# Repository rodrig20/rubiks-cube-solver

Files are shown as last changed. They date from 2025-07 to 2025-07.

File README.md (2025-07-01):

# Rubik's Cube Solver

Um sistema robótico completo para resolver automaticamente um Cubo de Rubik, controlado por um microcontrolador ESP32-CAM. Este projeto combina hardware robótico (motores, câmera) com software de resolução e uma interface web interativa para visualização e controlo.

## Funcionalidades

- **Resolução Automática**: Algoritmo ZZ para resolver qualquer configuração do Cubo de Rubik
- **Captura de Imagem**: Câmara ESP32-CAM para detetar automaticamente o estado do cubo
- **Controlo Robótico**: Sistema de motores para executar movimentos físicos no cubo
- **Interface Web**: Visualização 3D interativa e controlo remoto via navegador
- **Baralhamento**: Função para gerar configurações aleatórias

## Requisitos de Hardware

### Componentes Principais
- **Microcontrolador**: ESP32 com suporte a câmera (ESP32-CAM ou similar)
- **Câmara**: Módulo ESP32-CAM para deteção de cores
- **Motores**:
  - Motor de base para rotação do cubo
  - Motor de garra para segurar e girar faces
- **Estrutura Mecânica**: Suporte para o cubo, motores e câmara
- **LED**: Iluminação para captura de imagem (embutido no ESP32-CAM)

### Conectividade
- Rede Wi-Fi para comunicação com interface web

## Dependências de Software

### Arduino IDE
- Testatado no Arduino IDE 2.3.4
- Pacote de suporte para placas ESP32
- Bibliotecas necessárias:
  - `ArduinoJson` - Parsing de JSON
  - `LittleFS` - Sistema de ficheiros
  - `WiFi` - Conectividade Wi-Fi (ESP32)
  - `WebServer` - Servidor web (ESP32)
  - `esp_camera` - Controlo da câmera ESP32-CAM

### Ferramentas Python (opcional)
- Python 3.7+
- Dependências em `tools/requirements.txt`:
  - `beautifulsoup4` - Web scraping
  - `requests` - Requisições HTTP
  - `RubikTwoPhase` - Algoritmo de resolução

## Instalação

1. Instalar o Arduino IDE e o pacote de suporte para placas necessário
2. Instalar as bibliotecas necessárias através do Gestor de Bibliotecas do Arduino
3. Fazer clone deste repositório ou descarregar o código fonte
4. Carregar os ficheiros do sistema de ficheiros para o ESP32 utilizando a ferramenta de carregamento LittleFS
5. Compilar e carregar o sketch principal para a placa

## Utilização

### 1. Inicialização do Sistema
1. Ligar a placa ESP32
2. Aguardar inicialização (ver mensagens no Monitor Série)
3. Conectar à rede Wi-Fi "CubeSolver" (password: "#cubeSolver")
4. Notar o endereço IP mostrado no Monitor Série

### 2. Interface Web
1. Abrir navegador e aceder ao IP do ESP32 (ex: `192.168.4.1`)
2. A interface 3D do cubo será carregada
3. Utilizar controlos para:
   - Visualizar o cubo em 3D
   - Executar movimentos manuais
   - Capturar estado atual via câmara
   - Resolver automaticamente
   - Baralhar o cubo

### 3. API Endpoints
- `GET /cubestate` - Obter estado atual do cubo
- `POST /sendmove` - Executar sequência de movimentos
- `GET /solve` - Resolver o cubo e retornar solução
- `GET /scramble` - Baralhar o cubo
- `GET /capture` - Capturar imagem da câmera (debug)
- `POST /update_state` - Atualizar estado do cubo
- `GET /scan` - Faz o scan do estado do cubo via câmera

## Estrutura do Projeto

### Ficheiros Principais
- `rubiks-cube-solver.ino` - Sketch principal do Arduino
- `Robot.hpp/cpp` - Principal
- `Solver.hpp/cpp` - Algoritmo de resolução do cubo
- `Camera.hpp/cpp` - Controlo da câmara e processamento de imagem
- `Motor.hpp/cpp` - Classes base para controlo de motores
- `BaseMotor.hpp/cpp` - Motor de rotação da base
- `GrabberMotor.hpp/cpp` - Motor da garra

### Interface Web (`data/`)
- `index.html` - Página principal
- `css/style.css` - Estilos da interface
- `js/` - Bibliotecas JavaScript:
  - `css3.oz.js`, `oz.js`, `quaternion.js`, `rubik.js` - Cubo virtual
  - `custom.js` - Integração com ESP32

### Ferramentas (`tools/`)
- `get_zbll.py` - Geração de algoritmos ZBLL
- `requirements.txt` - Dependências Python

### Rede Wi-Fi
- Modificar SSID e password em `rubiks-cube-solver.ino`
- Configurar IP estático se necessário

## Créditos
- **Cubo Virtual**: Baseada em [ondras/rubik](https://github.com/ondras/rubik)

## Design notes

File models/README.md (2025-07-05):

# Modelos 3D

Esta pasta contém os arquivos STL necessários para a construção física do robô solucionador do Cubo Mágico.

## Arquivos Usados

### Arquivos Personalizados
- **ESP32Cam-suporte.stl** - Suporte para a base deslizante
- **ESP32Cam-deslizante.stl** - Base deslizante para controlar a câmera do ESP32-CAM

### Projeto Original

Os modelos 3D deste projeto são do trabalho original disponível no Thingiverse:

🔗 **[CUBOTino autonomous: 3D printed Rubik's cube solver](https://www.thingiverse.com/thing:5407226)**

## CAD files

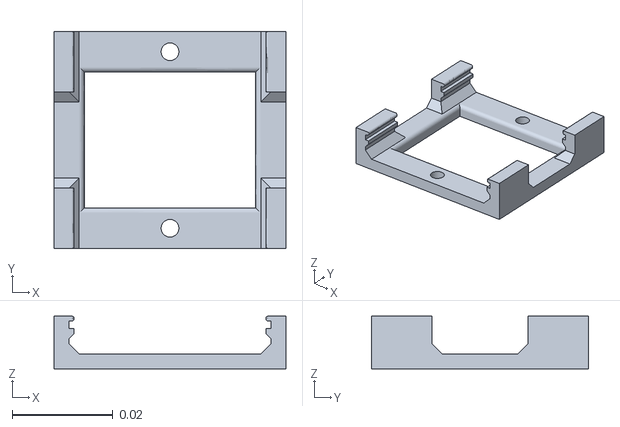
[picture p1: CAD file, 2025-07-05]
models/ESP32Cam-deslizante.stl
0.046 x 0.043 x 0.0105

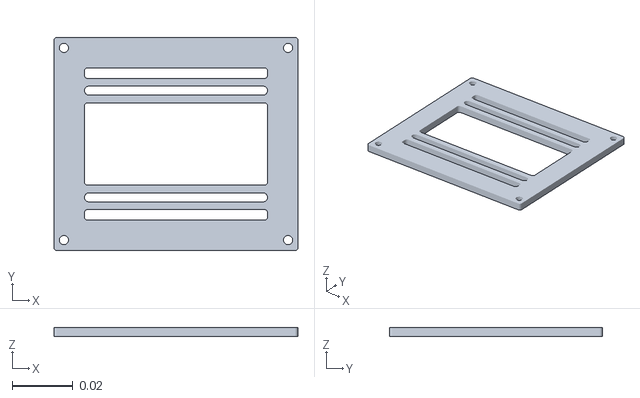
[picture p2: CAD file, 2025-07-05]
models/ESP32Cam-suporte.stl
0.08 x 0.07 x 0.003

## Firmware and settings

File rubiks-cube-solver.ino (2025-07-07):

#include <Arduino.h>
#include <LittleFS.h>
#include <WiFi.h>

#include "src/Robot.hpp"

Robot* robot = nullptr;

// Tenta gerar uma seed o mais próxima de aleatório
void randomSeed() {
    // Inicializar gerador de números aleatórios com seed única
    // Usar múltiplas fontes de aleatoriedade para garantir unicidade
    unsigned long seed = 0;

    // Usar tempo de inicialização (micros() para maior precisão)
    seed += micros();

    // Usar endereço MAC do WiFi
    uint8_t mac[6];
    WiFi.macAddress(mac);
    for (int i = 0; i < 6; i++) {
        seed = seed * 31 + mac[i];
    }

    // Usar ID único do chip ESP32
    seed += ESP.getEfuseMac();

    // Usar tempo de boot (em milissegundos)
    seed += millis();

    // Aplicar a seed
    srand(seed);

    Serial.printf("Seed inicializada: %lu\n", seed);
}

void setup() {
    // Iniciar o Serial
    Serial.begin(115200);
    delay(1000);
    Serial.println("\nIniciando ...");

    randomSeed();

    // Iniciar o LittleFS
    if (!LittleFS.begin()) {
        Serial.println("Falha ao montar LittleFS! A formatar...");
        LittleFS.format();
        if (!LittleFS.begin()) {
            Serial.println("Erro: Não foi possível montar LittleFS!");
            return;
        }
    }

    robot = new Robot();

    // Mensagem Final
    Serial.println("Servidor HTTP iniciado!");
}

void loop() {
    // Executar robô
    robot->run();
}

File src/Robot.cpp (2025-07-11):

#include "Robot.hpp"

#include <Arduino.h>
#include <Wire.h>
#include <esp_system.h>

#include <iostream>
#include <map>
#include <sstream>
#include <string>

#include "camera/Camera.hpp"
#include "motors/BaseMotor.hpp"
#include "motors/GrabberMotor.hpp"
#include "network/CubeServer.hpp"
#include "solver/Solver.hpp"

#define ERROR_LED_PIN 33
#define NO_ROBOT 0  // Indica se o esp32 está ligado ao robô

// Verifica se um dispositivo I2C está conectado
int device_is_present(uint8_t address) {
    Wire.beginTransmission(address);
    return (Wire.endTransmission() == 0);
}

// Pisca o led de Erro
void blink_erro(int times) {
    for (int i = 0; i < times; i++) {
        digitalWrite(ERROR_LED_PIN, LOW);
        delay(75);
        digitalWrite(ERROR_LED_PIN, HIGH);
        if (times - 1 != i) {
            delay(100);
        }
    }
}

// Inicia a comunicação I2C
Adafruit_PWMServoDriver* Robot::initI2C() {
    Wire.begin(14, 15);  // Inicializa I2C nos pinos 14 e 15

    if (!device_is_present(0x40)) {
        return nullptr;  // Ou lidar com erro como quiseres
    }

    Adafruit_PWMServoDriver* new_pwm = new Adafruit_PWMServoDriver(0x40);
    new_pwm->begin();
    new_pwm->setPWMFreq(50);
    return new_pwm;
}

// Move os dois motores para a posição padrão
void Robot::init_config() {
    virtual_lock_default();
    virtual_turn_90_aligned(0);
}

// Aplica um movimento ao cubo causado pelas rotações da base
void Robot::change_virtual_orientation(int changes[6]) {
    string temp = cube_state;
    for (int i = 0; i < 6; i++) {
        temp[i] = cube_state[changes[i]];
    }

    cube_state = temp;
}

// Aplica a uma sequencia de movimentos dos motores para uma certa face ficar
// para baixo
void Robot::rotate_to_side(const char side) {
    int side_idx;
    for (int i = 0; i < cube_state.size(); i++) {
        if (cube_state[i] == side) {
            side_idx = i;
            break;
        }
    }

    switch (side_idx) {
        // Topo
        case 0: {
            virtual_spin(2);
            int pattern0[6] = {5, 3, 2, 1, 4, 0};
            change_virtual_orientation(pattern0);
            break;
        }
        // Frente
        case 1: {
            virtual_spin(1);
            int pattern1[6] = {3, 0, 2, 5, 4, 1};
            change_virtual_orientation(pattern1);
            break;
        }
        // Direita
        case 2: {
            virtual_turn_90_aligned(1);
            virtual_spin(3);
            virtual_turn_90_aligned(0);
            int pattern2[6] = {4, 1, 0, 3, 5, 2};
            change_virtual_orientation(pattern2);
            break;
        }
        // Trás
        case 3: {
            virtual_spin(3);
            int pattern3[6] = {1, 5, 2, 0, 4, 3};
            change_virtual_orientation(pattern3);
            break;
        }
        // Esquerda
        case 4: {
            virtual_turn_90_aligned(1);
            virtual_spin(1);
            virtual_turn_90_aligned(0);
            int pattern4[6] = {2, 1, 5, 3, 0, 4};
            change_virtual_orientation(pattern4);
            break;
        }
    }
}

// Passar o movimento spin para o buffer
void Robot::virtual_spin(int times) {
    for (int i = 0; i < times; i++) {
        this->move_list += "U P ";
    }
}

// Passar o movimento lock para o buffer
void Robot::virtual_lock() { this->move_list += "L "; }

// Passar o movimento da garra para o default para o buffer
void Robot::virtual_lock_default() { this->move_list += "P "; }

// Passar o movimento em 90º alinhado para o buffer
void Robot::virtual_turn_90_aligned(int clockwise) {
    if (clockwise) {
        this->move_list += "A ";
    } else {
        this->move_list += "A' ";
    }
}

// Passar o movimento em 90º para o buffer
void Robot::virtual_turn_90(int clockwise) {
    if (clockwise) {
        this->move_list += "T ";
    } else {
        this->move_list += "T' ";
    }
}

// Passar o movimento em 180º para o buffer
void Robot::virtual_turn_180(int clockwise) {
    if (clockwise) {
        this->move_list += "D ";
    } else {
        this->move_list += "D' ";
    }
}

// Passar a captura de imagem para o buffer
void Robot::virtual_camera(int face) {
    this->move_list += "C" + std::to_string(face) + " ";
}

// Construtor
Robot::Robot() {
    pinMode(ERROR_LED_PIN, OUTPUT);
    this->cube = new Solver(Solver::solved_string());
    has_state = 1;
    this->server = new CubeServer(this, 80);

// Executa se o ESP32 está conectado ao robô
#if !NO_ROBOT
    this->pwm = initI2C();

    // Inicializar motores/câmara
    if (!pwm) {
        std::cout << "I2C não detetado. A reiniciar..." << std::endl;
        // Avisa do reinicio e volta a ligar
        blink_erro(2);
        esp_restart();
        return;
    }
    this->base = new BaseMotor(this->pwm, 0);
    this->grabber = new GrabberMotor(this->pwm, 1);

    this->cam = new Camera();
    if (!this->cam->initialized) {
        std::cout << "Câmara não detetada. A reiniciar..." << std::endl;
        // Avisa do reinicio e volta a ligar
        blink_erro(3);
        esp_restart();
        return;
    }

    init_config();

#endif

    // Pisca o LED para indicar que está pronto
    for (int i = 0; i < 3; i++) {
        analogWrite(LED_PIN, LED_BRIGHTNESS);
        delay(75);
        analogWrite(LED_PIN, 0);
        delay(75);
    }
}

// Baralha o cubo
std::string Robot::scramble(int size) {
    std::string move_sequence = cube->scramble(size);
    virtual_move(move_sequence);
    return move_sequence;
}

// Resolve o cubo
std::string Robot::solve() {
    std::string move_sequence = cube->solve();
    virtual_move(move_sequence);
    return move_sequence;
}

// Ativa a sequencia de motores para girar a face de baixo em 90º
void Robot::turn_face(int clockwise) {
    if (clockwise) {
        virtual_lock();
        virtual_turn_90(1);
        virtual_lock_default();
        virtual_turn_90_aligned(0);
        int pattern[6] = {0, 2, 3, 4, 1, 5};
        change_virtual_orientation(pattern);
    } else {
        virtual_turn_90_aligned(1);
        virtual_lock();
        virtual_turn_90(0);
        virtual_lock_default();
        virtual_turn_90_aligned(0);
        int pattern[6] = {0, 4, 1, 2, 3, 5};
        change_virtual_orientation(pattern);
    }
}
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

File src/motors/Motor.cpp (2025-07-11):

#include "Motor.hpp"

#include <Arduino.h>

// Construtor que armazen o motor_id e pwm
Motor::Motor(Adafruit_PWMServoDriver *pwm, int motor_id) {
    this->pwm = pwm;
    this->motor_id = motor_id;
}

void Motor::turn_with_speed_to(float angle, int speed_percent) {
    final_angle = angle;
    // Angulo inicial
    if (this->angle == -1) {
        steps_remaning = 1;
    } else {
        // Calcular o número de steps
        int divisor = (SERVO_STEP_SIZE * (speed_percent / 100.0f));
        steps_remaning = abs(angle - this->angle) / divisor;
    }
}

// Configura o motor girar para um angulo escolhido numa velocidade rápida
void Motor::turn_fast_to(float angle) { turn_with_speed_to(angle, 100); }

// Configura o motor girar para um angulo escolhido com metade da velocidade
void Motor::turn_slow_to(float angle) { turn_with_speed_to(angle, 50); }

// Aplica um delay com millis
void Motor::dly(int millis_time) { next_move_time = millis() + millis_time; }

// Aplica o próximo passo do movimento do motor
int Motor::step() {
    // Verifica se já passou o tempo definido
    if (next_move_time < millis()) {
        // Se o angulo já chegou ao fim atualiza
        if (current_angle == final_angle) {
            // Atualiza e retorna que já acabou
            this->angle = final_angle;
            return 1;
        }

        // Verifica se o angulo é muito pequeno ou for o ultimo step
        if (abs(final_angle - this->angle) < 30 || steps_remaning <= 1) {
            // Atualiza a var da posição atual e moev até ao final
            current_angle = final_angle;
            (*pwm).setPWM(motor_id, 0, angleToPulse(final_angle));
            dly(SERVO_MOVE_DELAY);
        } else {
            // Trocar a var da posição atual para o próximo passo
            current_angle += (final_angle - current_angle) / steps_remaning;
            steps_remaning--;

            (*pwm).setPWM(motor_id, 0, angleToPulse(current_angle));
            dly(SERVO_STEP_DELAY);
        }
    }

    return 0;
}

// Transforma angulo em pwm
uint16_t Motor::angleToPulse(float angle) {
    return SERVO_MIN + ((angle * (SERVO_MAX - SERVO_MIN)) / 270);
}

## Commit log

2025-03-26 Trocar Refactor.ino por rubiks-cube-solver.ino para que possa ser aberto no Arduino IDE
2025-03-26 Corrigir problemas de indentação
    [rubiks-cube-solver.ino]
2025-03-26 Corrigir nome da classe do WebServer do Esp8266
    [rubiks-cube-solver.ino]
2025-03-27 Atualizar conteudo do README para coincidir com o estado atual do projeto
2025-03-31 Começar o loop em 4, em vez de somar +4 em todos os usos
2025-03-31 Simplificar condição para identificar o local das edges de pares F2L
2025-05-08 Basic camera
2025-05-27 Fix color detection (endian problem)
    [Camera.cpp, Camera.hpp]
2025-05-27 Remove unused jpeg_quality field from ESP32 camera config
2025-05-27 Set sensor tuning params: brightness, contrast, saturation, white balance and auto exposure/gain
2025-05-29 Criar classe abstrata de um Motor
2025-05-29 Cria a classe dos dois tipos de motor (Base e Grabber)
2025-06-17 Fix alignment issues in BaseMotor
    [BaseMotor.cpp, Robot.cpp]
2025-06-17 Fix speed and timing synchronization between motors
    [Motor.cpp, Motor.hpp, Robot.cpp]
2025-06-17 Modularize code by moving functions into Camera module
2025-07-01 Change initial camera configs
2025-07-01 Change Custructor to start camera
2025-07-01 Add color grouping function based on HSV similarity to Camera
2025-07-01 Use multiple file, like original source-code Change page style Add new buttons
2025-07-02 Add route on esp32
2025-07-02 Refactor motor control to use asynchronous step-based execution (millis instead of delay)
2025-07-04 Add camera initialized flag
2025-07-04 Add I2C and camera verification
2025-07-04 Add error LED - 2 times: I2C Error - 3 times: Camera Error
    [Robot.cpp]
2025-07-04 Fix Camera blocking
2025-07-05 Add custom .stl models
    [ESP32Cam-deslizante.stl, ESP32Cam-suporte.stl]
2025-07-09 Eliminate unnecessary position resets during move sequence
    [Robot.cpp]
2025-07-09 Replace complex move sequences with simpler equivalents
    [BaseMotor.cpp, Motor.cpp, Robot.cpp]
